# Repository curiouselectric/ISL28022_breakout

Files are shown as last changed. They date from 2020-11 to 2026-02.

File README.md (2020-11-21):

# ISL28022_breakout
This is a breakout board for the ISL28022 DC Power monitoring IC with I2C

The ISL28022 from Renesas has a datasheet available here: https://www.renesas.com/us/en/products/amplifiers-buffers/all-amplifiers/digital-power-monitors/device/ISL28022.html

It is a DC power monitoring IC, which measures current and voltage and calculates power. The data is read at either 14 or 15 bit resolution. Data can be obtained via an I2C connection.

The maximum voltage is 60V DC and the current can be up to 320mV measured across a current shunt.

This folder contains the PCB design files for a simple break out board which can be connected to a microcontroller of your choice.

It is available to buy here: https://www.curiouselectric.co.uk/

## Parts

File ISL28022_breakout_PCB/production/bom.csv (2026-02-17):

Designator | Footprint | Quantity | Value | LCSC Part #
C1 | SM_C_0805 | 1 | 100n
C2 | SM_R_1206 | 1 | 2.2u
C3 | SM_R_1206 | 1 | 1u
C4, C5 | SM_C_0805 | 2 | 10n
J1, J2 | SIL-4_Grove_Labelled_Correct | 2 | DATA
J3 | SM_SOLDER_ID_4_WAY | 1 | ID_A0
J4 | SM_SOLDER_ID_4_WAY | 1 | ID_A1
J5 | PCB_60x55_outline | 1 | PCB
J6 | 2019_011_16_CuriousElectricCompany_Logo_Round_Logo_No_words_KiCAD_10mm_PCBLogo | 1 | LOGO1
J7 | TCEC_Words_13mm | 1 | LOGO2
J8 | TH_SIL-2_screw_terminal_32A_LARGE | 1 | INPUT
J9 | TH_SIL-2_screw_terminal_32A_LARGE | 1 | OUTPUT
R1, R2 | SM0805 | 2 | 4.7k
R3, R4, R5 | SM0805 | 3 | 470R
R6 | Rshunt_universal | 1 | R_SHUNT
U1 | MSOP10-0.5 | 1 | ISL28022

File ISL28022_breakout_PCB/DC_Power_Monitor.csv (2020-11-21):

Source: | G:\My Drive\Work - Kits\PRODUCTS\Prototype\DC_Power_Monitor\DC_Power_Monitor.sch
Date: | 26/10/2020 18:13
Tool: | Eeschema (5.1.0)-1
Generator: | C:\Program Files\KiCad\bin\scripting\plugins/bom_csv_grouped_by_value.py
Component Count: | 21
Individual Components:
Item | Qty | Reference(s) | Value | LibPart | Footprint | Datasheet | Code | Cost | Description | Notes | Supplier
 |  | C1 | 100n | Device:C | REInnovationFootprint:SM_C_0805 | http://www.farnell.com/datasheets/1870456.pdf | 2320793 | ~ | 25V | ~ | Farnell
 |  | C2 | 2.2u | Device:C | REInnovationFootprint:SM0805 | http://www.farnell.com/datasheets/1769893.pdf | 2426966RL | ~ | 100V | ~ | Farnell
 |  | C3 | 1u | Device:C | REInnovationFootprint:SM_R_1206 | http://www.farnell.com/datasheets/84526.pdf | 1657939 | ~ | 100V | ~ | Farnell
 |  | C4 | 10n | Device:C | REInnovationFootprint:SM0805 | http://www.farnell.com/datasheets/1870456.pdf | 2320786 | ~ | 100V | ~ | Farnell
 |  | C5 | 10n | Device:C | REInnovationFootprint:SM0805 | http://www.farnell.com/datasheets/1870456.pdf | 2320786 | ~ | 100V | ~ | Farnell
 |  | J1 | DATA | Connector_Generic:Conn_01x04 | REInnovationFootprint:SIL-4_Grove_Labelled | ~
 |  | J2 | DATA | Connector_Generic:Conn_01x04 | REInnovationFootprint:SIL-4_Grove_Labelled | ~
 |  | J3 | ID_A0 | Connector_Generic:Conn_01x05 | REInnovationFootprint:TH_SIL_5_1mm | ~
 |  | J4 | ID_A1 | Connector_Generic:Conn_01x05 | REInnovationFootprint:TH_SIL_5_1mm | ~
 |  | J5 | PCB | Connector_Generic:Conn_01x01 | REInnovationFootprint:PCB_50x50_outline | ~
 |  | J6 | LOGO1 | Connector_Generic:Conn_01x01 | CuriousElectric3:2019_011_16_CuriousElectricCompany_Logo_Round_Logo_No_words_KiCAD_10mm_PCBLogo | ~
 |  | J7 | LOGO2 | Connector_Generic:Conn_01x01 | CuriousElectric3:TCEC_Words_13mm | ~
 |  | J8 | INPUT | Connector_Generic:Conn_01x02 | REInnovationFootprint:TH_CONN_2W | ~
 |  | J9 | OUTPUT | Connector_Generic:Conn_01x02 | REInnovationFootprint:TH_CONN_2W | ~
 |  | R1 | 4.7k | Device:R | REInnovationFootprint:SM0805 | http://www.farnell.com/datasheets/1849611.pdf | 2447385 | ~ | 100mW | ~ | Farnell
 |  | R2 | 4.7k | Device:R | REInnovationFootprint:SM0805 | http://www.farnell.com/datasheets/1849611.pdf | 2447385 | ~ | 100mW | ~ | Farnell
 |  | R3 | 470R | Device:R | REInnovationFootprint:SM0805 | http://www.farnell.com/datasheets/1849611.pdf | 2447374 | ~ | 100mW | ~ | Farnell
 |  | R4 | 470R | Device:R | REInnovationFootprint:SM0805 | http://www.farnell.com/datasheets/1849611.pdf | 2447374 | ~ | 100mW | ~ | Farnell
 |  | R5 | 470R | Device:R | REInnovationFootprint:SM0805 | http://www.farnell.com/datasheets/1849611.pdf | 2447374 | ~ | 100mW | ~ | Farnell
 |  | R6 | R_SHUNT | Device:R | matts_components:Rshunt_universal | http://www.farnell.com/datasheets/1755795.pdf | 2331878 | ~ | 500mW | ~ | Farnell
 |  | U1 | ISL28022 | matts_components:ISL28022 | REInnovationFootprint:MSOP10-0.5 | http://www.farnell.com/datasheets/1758637.pdf | 2373594 | ~ | I2C power monitor | ~ | Farnell
Collated Components:
Item | Qty | Reference(s) | Value | LibPart | Footprint | Datasheet | Code | Cost | Description | Notes | Supplier
1 | 1 | C1 | 100n | Device:C | REInnovationFootprint:SM_C_0805 | http://www.farnell.com/datasheets/1870456.pdf | 2320793 | ~ | 25V | ~ | Farnell
2 | 1 | C2 | 2.2u | Device:C | REInnovationFootprint:SM0805 | http://www.farnell.com/datasheets/1769893.pdf | 2426966RL | ~ | 100V | ~ | Farnell
3 | 1 | C3 | 1u | Device:C | REInnovationFootprint:SM_R_1206 | http://www.farnell.com/datasheets/84526.pdf | 1657939 | ~ | 100V | ~ | Farnell
4 | 2 | C4, C5 | 10n | Device:C | REInnovationFootprint:SM0805 | http://www.farnell.com/datasheets/1870456.pdf | 2320786 | ~ | 100V | ~ | Farnell
5 | 2 | J1, J2 | DATA | Connector_Generic:Conn_01x04 | REInnovationFootprint:SIL-4_Grove_Labelled | ~
6 | 1 | J3 | ID_A0 | Connector_Generic:Conn_01x05 | REInnovationFootprint:TH_SIL_5_1mm | ~
7 | 1 | J4 | ID_A1 | Connector_Generic:Conn_01x05 | REInnovationFootprint:TH_SIL_5_1mm | ~
8 | 1 | J5 | PCB | Connector_Generic:Conn_01x01 | REInnovationFootprint:PCB_50x50_outline | ~
9 | 1 | J6 | LOGO1 | Connector_Generic:Conn_01x01 | CuriousElectric3:2019_011_16_CuriousElectricCompany_Logo_Round_Logo_No_words_KiCAD_10mm_PCBLogo | ~
10 | 1 | J7 | LOGO2 | Connector_Generic:Conn_01x01 | CuriousElectric3:TCEC_Words_13mm | ~
11 | 1 | J8 | INPUT | Connector_Generic:Conn_01x02 | REInnovationFootprint:TH_CONN_2W | ~
12 | 1 | J9 | OUTPUT | Connector_Generic:Conn_01x02 | REInnovationFootprint:TH_CONN_2W | ~
13 | 2 | R1, R2 | 4.7k | Device:R | REInnovationFootprint:SM0805 | http://www.farnell.com/datasheets/1849611.pdf | 2447385 | ~ | 100mW | ~ | Farnell
14 | 3 | R3, R4, R5 | 470R | Device:R | REInnovationFootprint:SM0805 | http://www.farnell.com/datasheets/1849611.pdf | 2447374 | ~ | 100mW | ~ | Farnell
15 | 1 | R6 | R_SHUNT | Device:R | matts_components:Rshunt_universal | http://www.farnell.com/datasheets/1755795.pdf | 2331878 | ~ | 500mW | ~ | Farnell
16 | 1 | U1 | ISL28022 | matts_components:ISL28022 | REInnovationFootprint:MSOP10-0.5 | http://www.farnell.com/datasheets/1758637.pdf | 2373594 | ~ | I2C power monitor | ~ | Farnell

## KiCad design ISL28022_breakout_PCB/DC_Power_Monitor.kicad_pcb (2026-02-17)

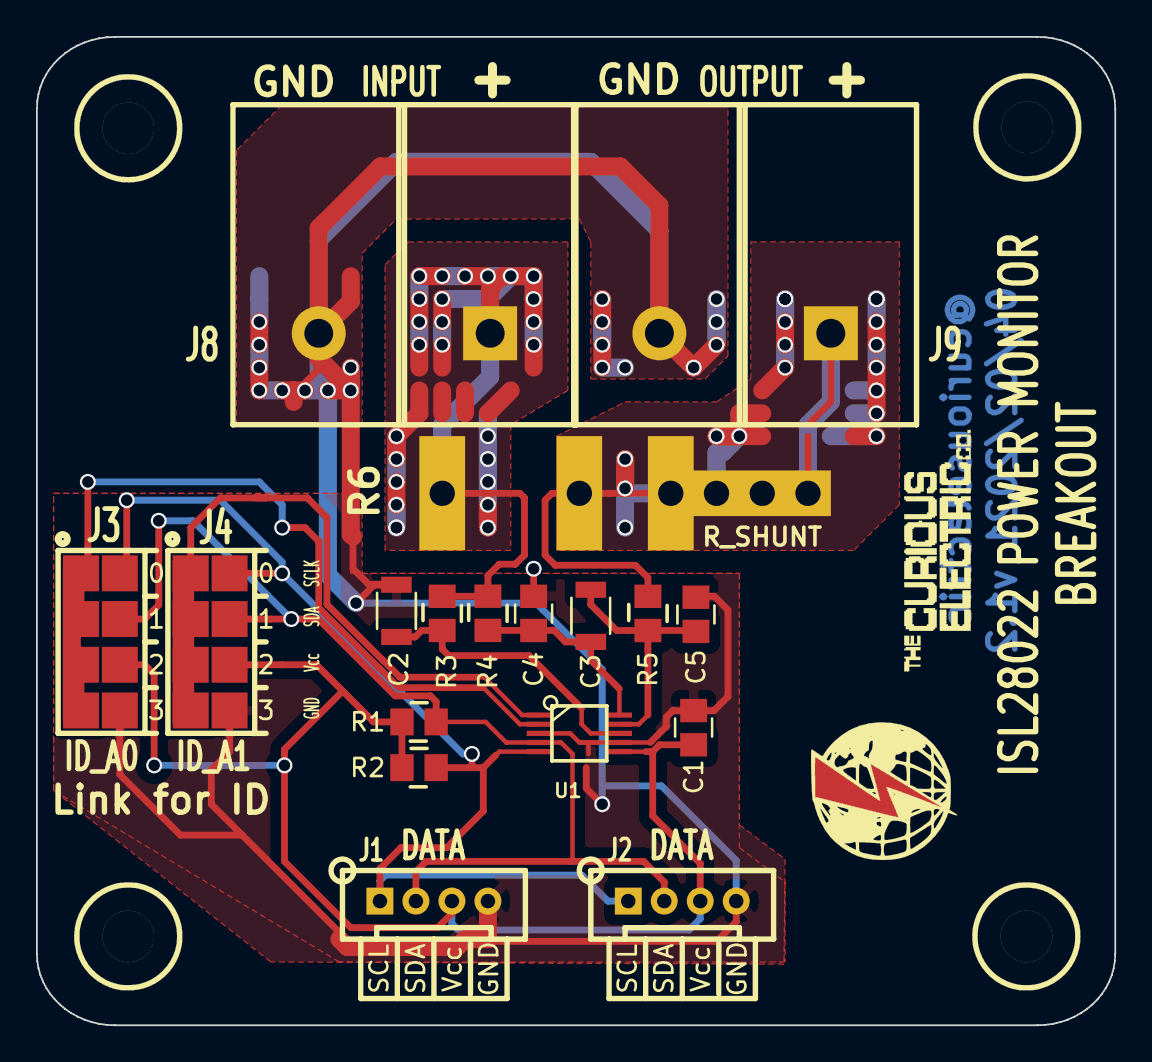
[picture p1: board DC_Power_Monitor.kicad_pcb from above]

Board: 2 copper layers, 59.9 x 54.9 mm, 21 parts (1 on the bottom side), 11 nets.

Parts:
C1: 100n; SM_C_0805
C2: 2.2u; SM_R_1206
C3: 1u; SM_R_1206
C4, C5: 10n; SM_C_0805
J1, J2: DATA; SIL-4_Grove_Labelled_Correct
J3: ID_A0; SM_SOLDER_ID_4_WAY
J4: ID_A1; SM_SOLDER_ID_4_WAY
J5: PCB; PCB_60x55_outline
J6: LOGO1; 2019_011_16_CuriousElectricCompany_Logo_Round_Logo_No_words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
J7: LOGO2; TCEC_Words_13mm
J8: INPUT; TH_SIL-2_screw_terminal_32A_LARGE
J9: OUTPUT; TH_SIL-2_screw_terminal_32A_LARGE
R1, R2: 4.7k; SM0805
R3, R4, R5: 470R; SM0805
R6: R_SHUNT; Rshunt_universal
U1: ISL28022; MSOP10-0.5

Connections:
/Ishn: J9.1, R5.2, R6.2
/Ishp: J8.1, R3.2, R4.2, R6.1
/SCLK: J1.1, J2.1, J3.2, J4.2, R2.1, U1.5
/SDA: J1.2, J2.2, J3.3, J4.3, R1.1, U1.4
/Vcc: C1.2, J1.3, J2.3, J3.4, J4.4, R1.2, R2.2, U1.6
GND: C1.1, C2.2, C4.2, C5.2, J1.4, J2.4, J3.5, J4.5, J8.2, J9.2, U1.3, U1.7
unnamed: C2.1, R3.1, U1.8
unnamed: C3.1, C4.1, R4.1, U1.10
unnamed: C3.2, C5.1, R5.1, U1.9
unnamed: J3.1, U1.2
unnamed: J4.1, U1.1

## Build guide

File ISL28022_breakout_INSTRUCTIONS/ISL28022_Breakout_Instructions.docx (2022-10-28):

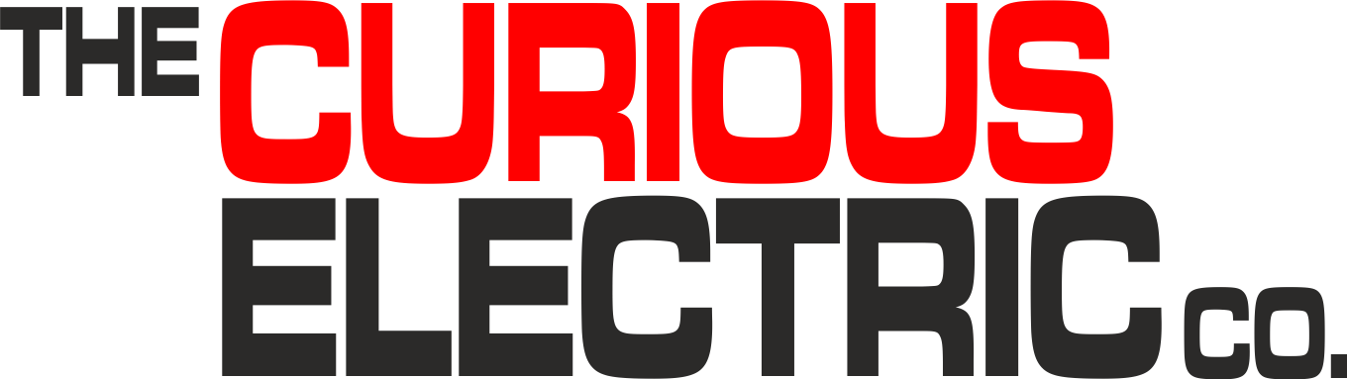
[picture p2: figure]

| DC Power Monitor Instructions

Date: | 28/10/2022 | Version: | 1.2 | By: | Matt Little

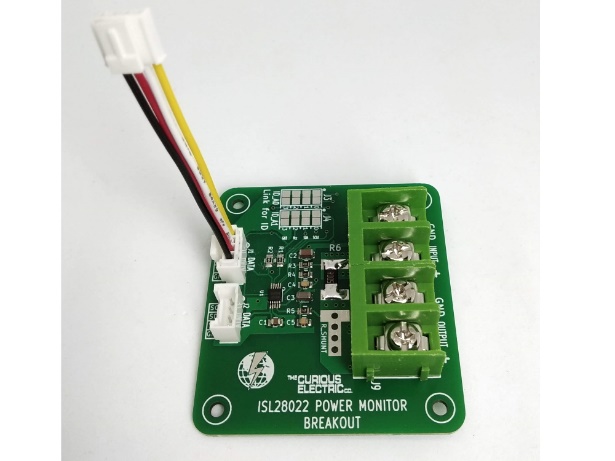
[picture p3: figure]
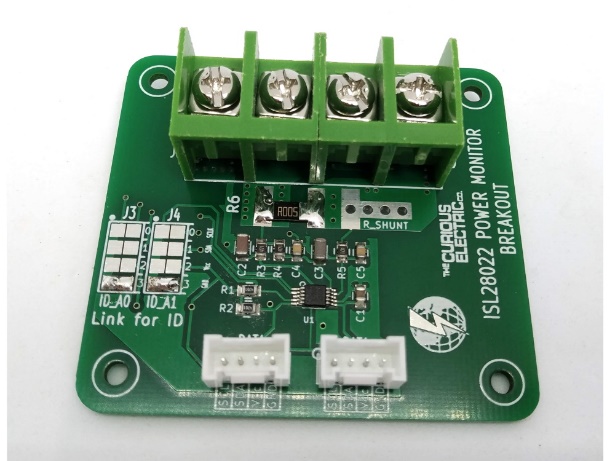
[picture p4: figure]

Need to measure DC voltage, current and power?

We needed to for a renewable energy project and saw the ISL28022 from Renesas:

https://www.renesas.com/eu/en/document/dst/isl28022-datasheet

This is a bidirectional high-side and low-side digital current sense and voltage monitor with an I2C serial interface.

It can measure up to 60V DC and current through a shunt resistor with a shunt voltage of up to 320mV. We supply a 5mOhm shunt resistor, which can measure up to 32 A. This is measured with a high-accuracy analogue to digital converter with better than 0.3%. It can have the shunt in the high or low side and can cope with negative shunt voltages.

We have put this IC on a circuit board with 25A rated screw terminals, ‘Grove’ connectors for the I2C interface. It can work with 3-5V power supply. We have added small smoothing capacitors and interface circuitry. This is surface mount & we have already added these components.

This is a reasonably simple kit which requires some soldering.

It will need wiring to a microcontroller of your choice through an I2C interface. We provide simple example Arduino Uno code.

It should take under 1 hour to build.

Not suitable for under 12 years old.

# Parts included:

| | | PCB with components

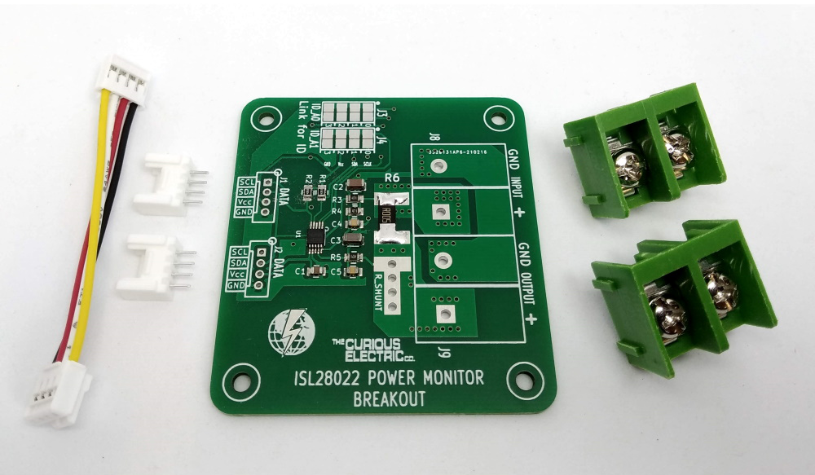
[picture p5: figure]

Grove connection cable
| | | | | | | Power Terminals (25A max) X 2
| | Grove Data connectors x 2 | | | 5 mOhm Shunt resistor (not shown)

# PCB Parts List:

Ref | Item | Quantity | Ref | Item | Quantity
C1 | 100nf capacitor (SMD Soldered) | 1 | J8, J9 | Input and Output 25A terminals | 2
C2 | 2.2uf capacitor (SMD Soldered) | 1 | R1, R2 | 4.7k (SMD – Not Used) | 2
C3 | 1uf capacitor (SMD Soldered) | 1 | R3, R4, R5 | 470R (SMD Soldered) | 3
C4, C5 | 10nf capacitor (SMD Soldered) | 2 | R6 | Shunt Resistor. (0.005 Ohm supplied). | 1
J1, J2 | DATA - Grove connector 4 way | 2 | U1 | ISL28022 Power Monitor (SMD Soldered) | 1
| PCB | 1

# Tools required:

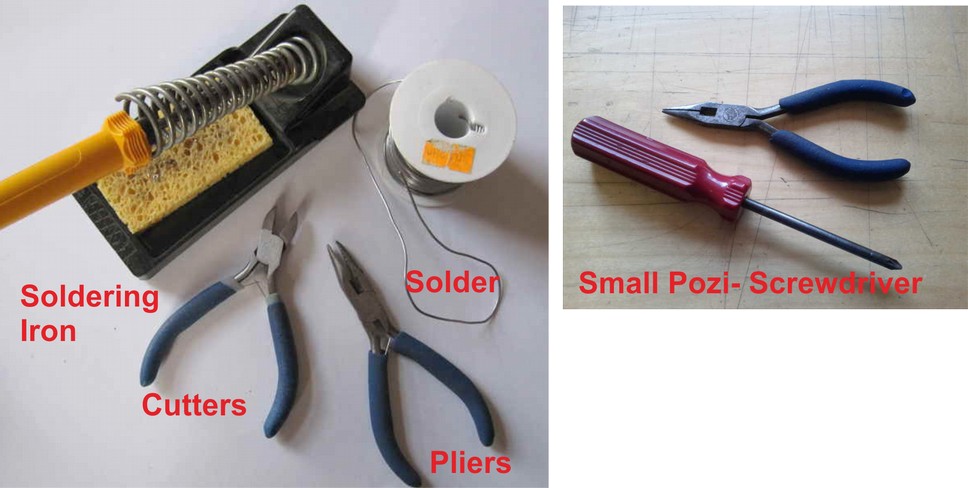
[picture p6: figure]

| | Long-nosed Pliers
Soldering Iron | | Posi-drive Screwdriver
Solder
Side cutters
Scissors (not shown)

# Instructions:

Step: 1 | Solder ‘Grove’ data connectors

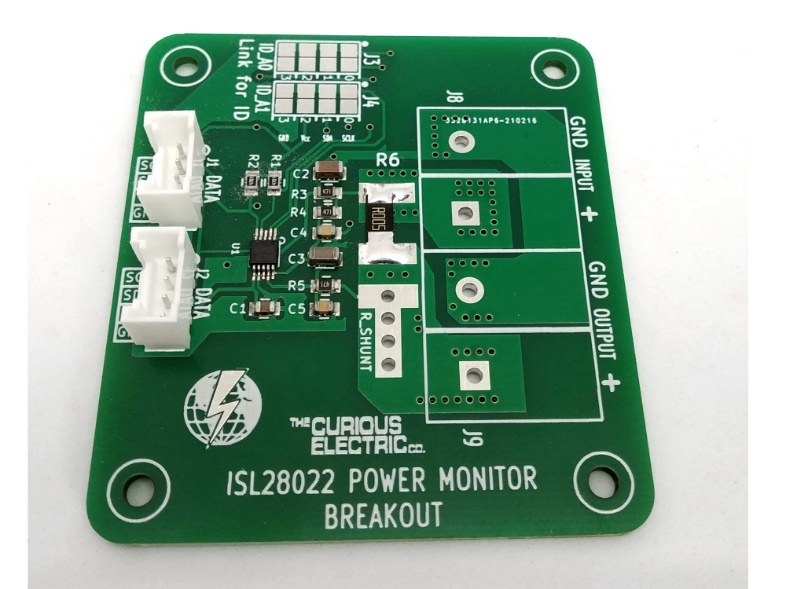
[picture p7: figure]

| | There are two 4-way ‘Grove’ connectors. This is a standard connector supplied by Seeed Studio (https://wiki.seeedstudio.com/Grove_System/) with lots of compatible boards. Place them into the 4-way holes in the PCB. Ensure that the silk-screen showing the notch is followed with the white connector. There is a small clip on the plug which needs to align with the notch on the socket.

Step: 2 | Solder shunt resistor

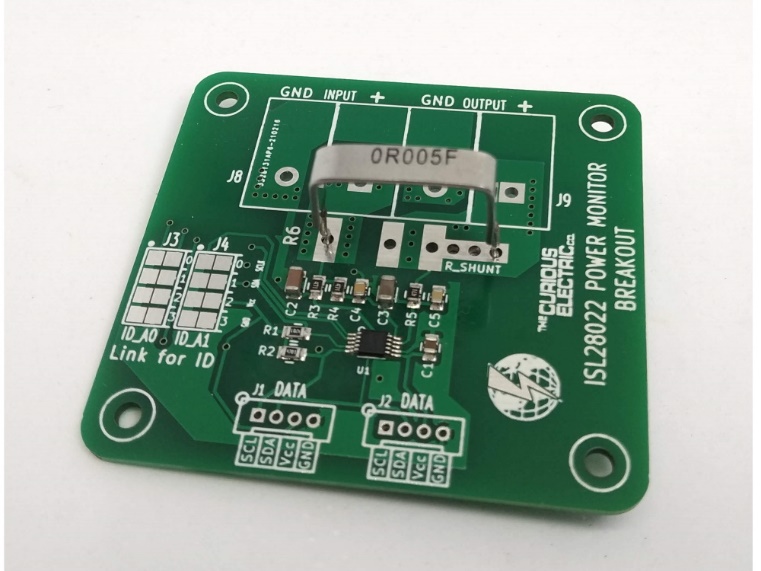
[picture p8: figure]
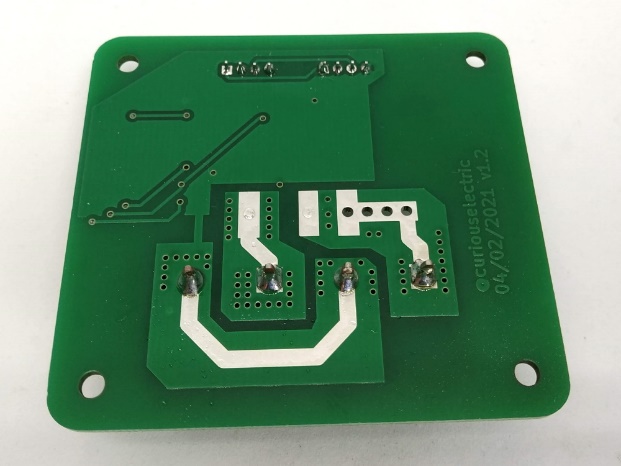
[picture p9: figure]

We provide a 5 milli-Ohm shunt resistor which is rated for 5W. This needs to be soldered into the universal shunt pads, as shown here. You can fit other resistors here, but you may need to change the example code. If you are going to use high currents (>10 A for extended periods), then you can add solder to the tracks to increase the current carrying capacity. Note: It is not recommended to use this board for more than 25 A for any length of time.

Step: 3 | Solder power terminals

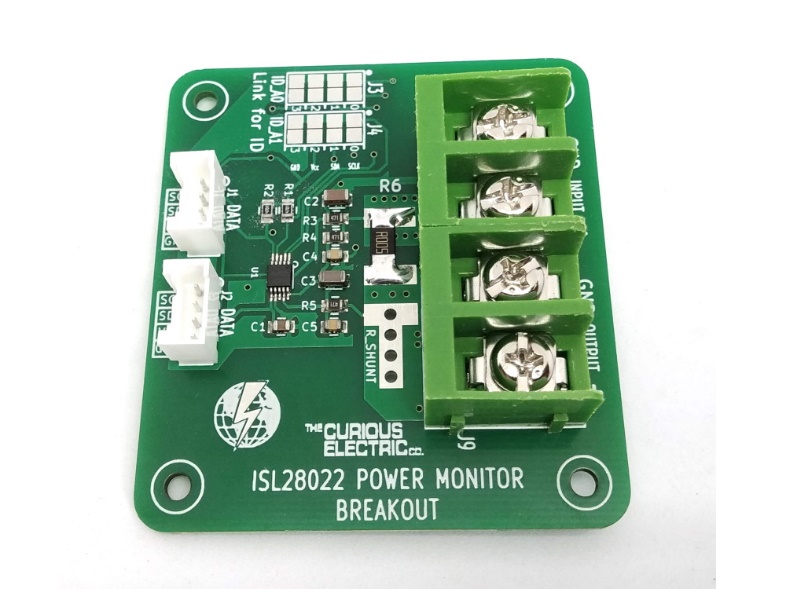
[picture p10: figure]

| | There are two 2-way screw terminal connectors for the power connections. These are rated to 25 A DC. They clip together with a small slot. They then fit through the holes. These can then be soldered. They may require quite a lot of solder and a powerful soldering iron, as they are large connectors.

Step: 4 | Solder ID connections

Each IC can have a different I2C address. This is enabled by connecting A0 and A1 to: GND, Vcc, SDA or SCL. This gives a total of 16 different addresses. These are given in the IC data sheet.

This is done by using a solder ‘blob’ to join two pads.

The connections to make depend upon the number of sensors you would like to attach.

Typically, one sensor is attached, so you just need a solder blob link connect A0 to GND (Link ID_A0 at pad 3) and A1 to GND (Link ID_A1 at pad 3), as per the code example. This is already done for you.

Remove the solder blob with a solder sucker if you want to change the ID.

Then add solder blobs as per the table under the photo.

There are more options than this, so check the data sheet for more information.

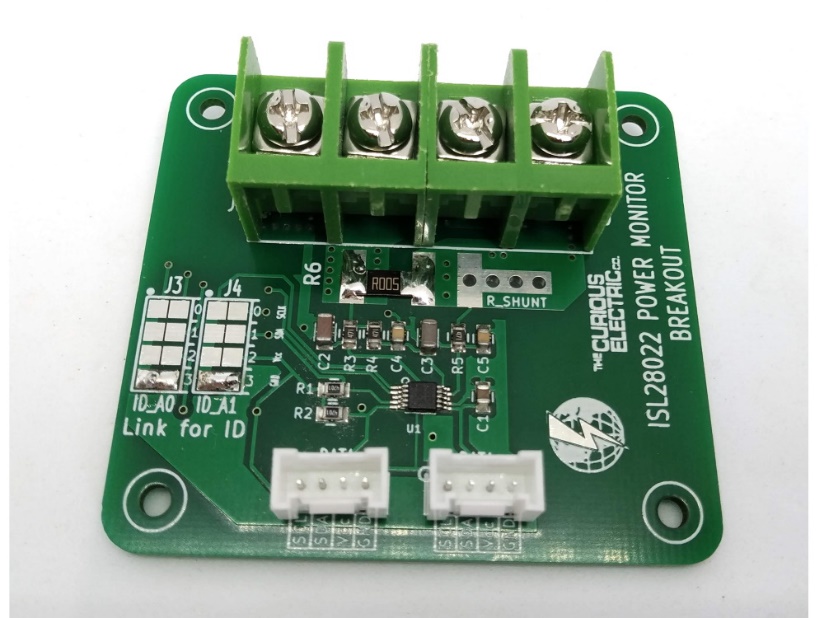
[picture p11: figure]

Link = add solder blob to the connector.

ID_A0 | ID_A1 | IC Address
Link 3 | Link 3 | 1000 000
Link 2 | Link 3 | 1000 001
Link 1 | Link 3 | 1000 010
Link 0 | Link 3 | 1000 011
Link 3 | Link 2 | 1000 100
Link 2 | Link 2 | 1000 101
Link 1 | Link 2 | 1000 110
Link 0 | Link 2 | 1000 111

Step: 5 | PCB is finished!

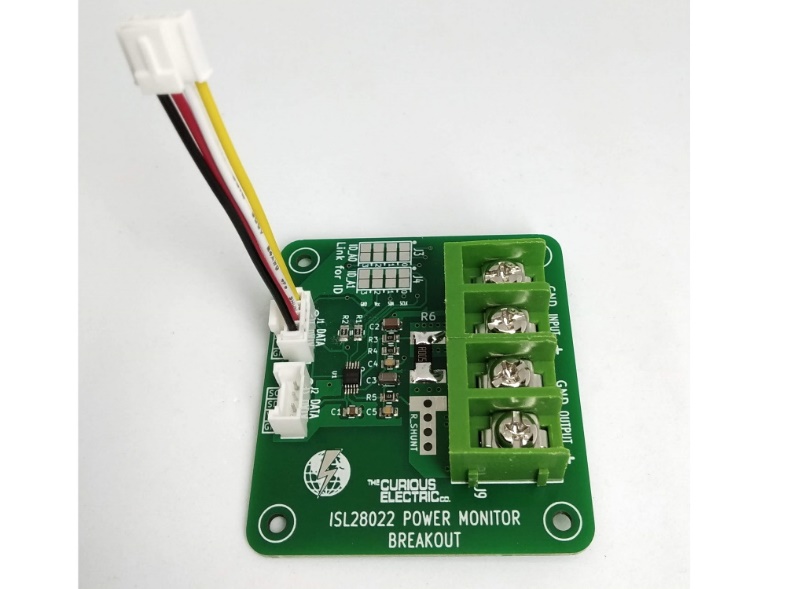
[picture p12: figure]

| | Have a nice cup of tea! You are now ready to try it out!

# Communication Instructions:

Step: 6 | Connect to your microcontroller of choice!

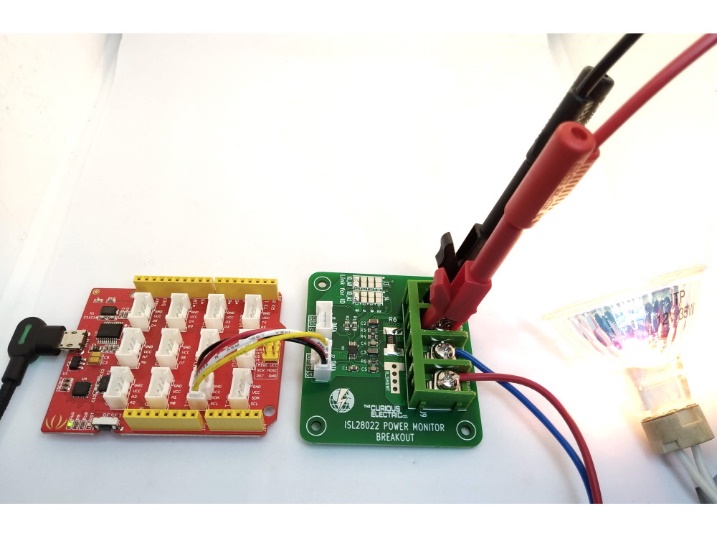
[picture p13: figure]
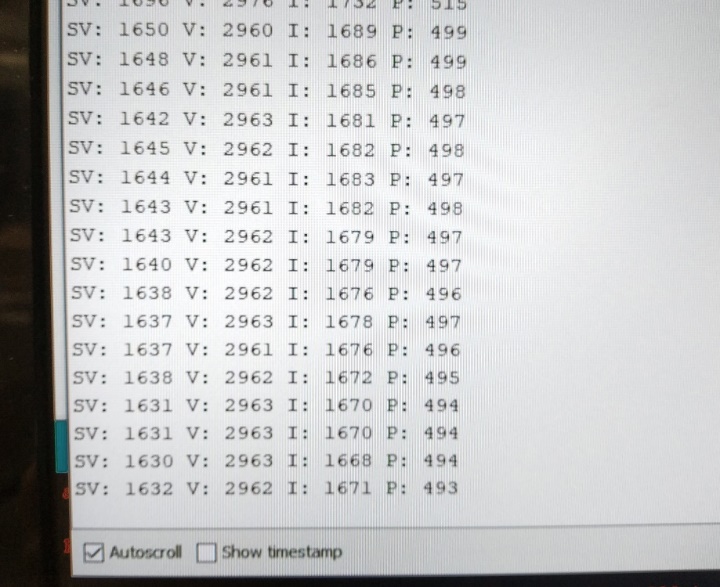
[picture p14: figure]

If you have a Grove board with an I2C connection, then please use the short connector wire to link the sensor with an I2C connection. The photo here shows testing with a “Seeeduino Lotus” board. Otherwise, you will need to make connections between GND, Vcc (which can be 3V3 or 5V) and then to the data (SDA) and clock (SCL) lines of your microcontroller. Upload the example code (this was tested with an Arduino Uno & Seeduino Lotus & Arduino Nano 33 IoT). You should see some serial data (at 9600 baud rate) showing the Shunt Voltage (mV), Voltage (V), Current (A) and Power (W).

# Testing & Fault Finding

These units have been tested in our lab, so hopefully no issues for you!

You want to try the simple example code and check that the readings look correct for the voltage and load you apply.

Any issues at all then try the following:

- Check soldering.
- Check power connections.
- Check I2C connections.
- Check microcontroller code updated correctly.

# Source Code and Design Files

These can be found, along with these instructions, in the repository here:

https://github.com/curiouselectric/ISL28022_breakout

# Contact details:

This kit has been designed and produced by:

The Curious Electric Company

hello@curiouselectric.co.uk

www.curiouselectric.co.uk

We would like you to be happy with this kit. If you are not happy for any reason, then please contact us and we will help to sort it out.

Please email hello@curiouselectric.co.uk with any questions or comments.

Please tweet us at @curiouselectric

If any parts are missing from your kit, then please email hello@curiouselectric.co.uk with details, including where the kit was purchased.

More information can be found via www.curiouselectric.co.uk

# Circuit Schematic:

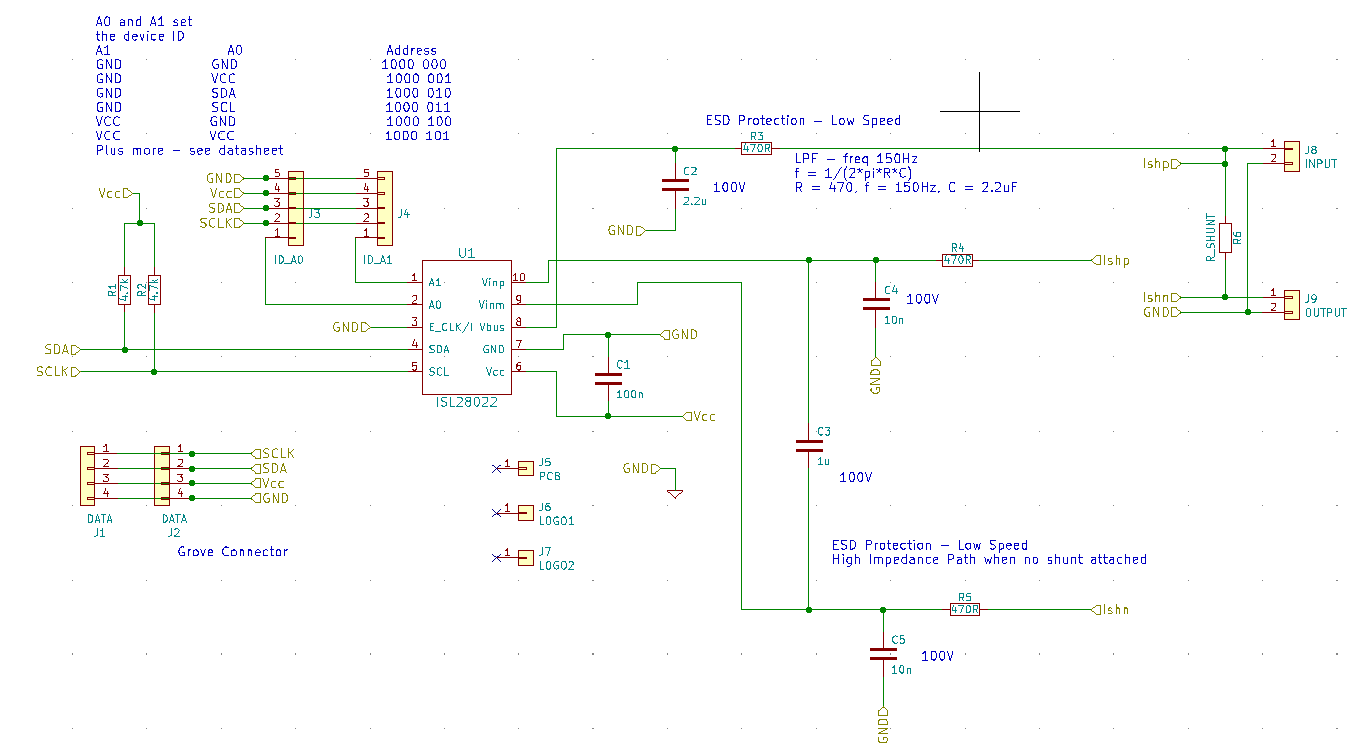
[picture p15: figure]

# PCB:

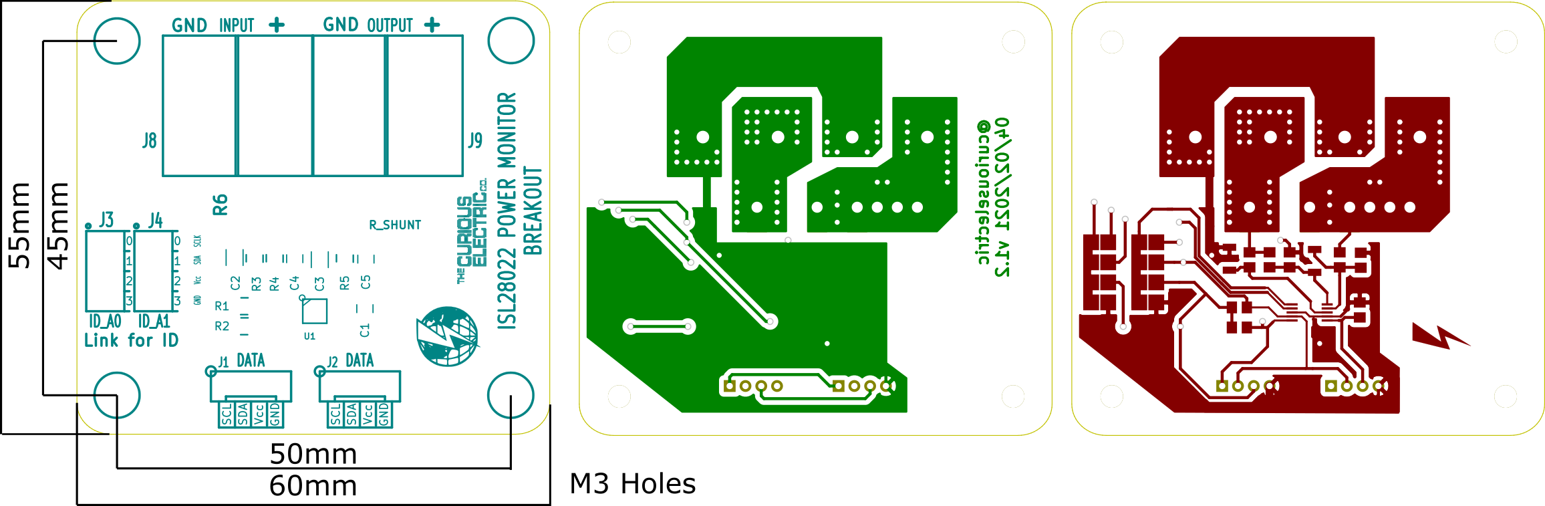
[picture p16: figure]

(Not to scale)

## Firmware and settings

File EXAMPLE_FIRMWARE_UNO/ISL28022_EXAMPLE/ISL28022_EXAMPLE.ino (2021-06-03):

/*
    Example code for Arduino Uno to talk to ISL28022 Power Monitor IC
    Details and PCB design and instructions here
    https://github.com/curiouselectric/ISL28022_breakout  
*/

#include <Arduino.h>
#include <Wire.h>
#include "isl28022DL.h"

// The baud rate for serial communications
#define SERIAL_BAUD       9600

// This information is for the ISL28022 unit:
#define ADDRESS_ISL0    0b1000000  // This is the device address for A0 = GND A1 = GND
//#define ADDRESS_ISL1    0b1000001  // This is the device address for A0 = VCC A1 = GND
//#define ADDRESS_ISL2    0b1000010  // This is the device address for A0 = SDA A1 = GND

float dataValue;

void setup()
{
  // initialize serial communication:
  Serial.begin(9600);
  // Start up the ISL28022 Power monitor ICs
  power_monitor.begin(ADDRESS_ISL0);
}

void loop()
{
  dataValue = power_monitor.readRegister(ADDRESS_ISL0, SHUNTVOLTREG); 
  dataValue = power_monitor.readRegister(ADDRESS_ISL0, BUSVOLTREG);
  dataValue = power_monitor.readRegister(ADDRESS_ISL0, CURRENTREG);
  dataValue = power_monitor.readRegister(ADDRESS_ISL0, POWERREG);
  Serial.println();
  delay(1000);  // Check every second!
}

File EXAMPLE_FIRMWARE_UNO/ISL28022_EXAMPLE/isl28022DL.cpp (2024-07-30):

#include "isl28022DL.h"

void power_isl28022::begin(int _address)
{
  // Set up ISL28022 Power Monitor IC
  // Test the ISL28022
  Wire.begin();  // Join the bus as Master
  delay(20);  // Short settling delay
  // Reset the Configuration Register

  Serial.print("Start: ");
  Serial.println(_address);

  Wire.beginTransmission(_address);  // Start write to address 0b1000000
  Wire.write(0x00);    // Write to the calibration register

  // Set up everything:
  // RST/BRNG1/BRNG0/PG1/PG0/BADC3/BADC2/BADC1/BADC0/SADC3/SADC2/SADC1/SADC0/MODE2/MODE1/MODE0
  // Set it to:
  // 0b1000000000000000
  // Perform a system reset:
  Wire.write (0b10000000);
  Wire.write (0b00000000);
  Wire.endTransmission();

  // Set up the Configuration Register
  Wire.beginTransmission(_address);  // Start write to address 0b1000000
  Wire.write(0x00);    // Write to the calibration register

  // Set up everything:
  // RST/BRNG1/BRNG0/PG1/PG0/BADC3/BADC2/BADC1/BADC0/SADC3/SADC2/SADC1/SADC0/MODE2/MODE1/MODE0
  // Shunt with 320mV range so need to set PG1 = 1 and PG0 = 1 (from datasheet)
  // Set it to:
  // 0b 0 11 11 0011 0011 111
  Wire.write (0b01111001);
  Wire.write (0b10011111);
  Wire.endTransmission();

  // Set up the Calibration Register
  // This allows the Power and Current registers to be used
  Wire.beginTransmission(_address);  // Start write to IC address 
  Wire.write(0x05);                 // Write to the calibration register

  // OLD values were:
  // 4474 = 117A in HEX
  // Binary: 0001 0001 0111 1010

  // 5mOhm Shunt with 320mV range
  // Calibration register needs to be set to 4194 (dec) = 1062 (hex)
  Wire.write (0x10);
  Wire.write (0x62);

  Wire.endTransmission();
}

// Read data from a specified register and apecified IC address:
float power_isl28022::readRegister(int _address, int _reg)
{
  // This subroutine reads data from device with I2C address ADDRESS
  // It reads the data from the device register ISL28022register
  byte firstByte = 0;
  byte secondByte = 0;
  uint16_t valueInt16;
  float  valueFloat;

  Wire.beginTransmission(_address);  // Start write to address 0b1000000
  Wire.write(_reg);     // Read the Bus Voltage register
  Wire.endTransmission();
  Wire.requestFrom(_address, 2);    // Read two bytes of data

  while (!Wire.available())          // Wait until there is data returned
  {
  }
  firstByte = Wire.read();          // Read and store the data
  secondByte = Wire.read();

  if (_reg == SHUNTVOLTREG)
  {
    Serial.print(F("SV: "));
    // ****THIS DEPENDS UPON THE SADC BITS*******
    // ****RANGE = 11 (full scale up to +/-160mV)
    // The bus voltage is a 15 bit value which needs to be converter.
    // Bit 16 is a sign bit (2's complement?)
    // Need to add them together, with the correct weighting factor (256)
    valueInt16 = firstByte * 256 + secondByte; // Convert to a value
    // Each bit is (160mV / 2^15)
    // So value * 0.00001V = shunt voltage
    // This is too small, so keep number in milli Volts
    valueFloat = ((valueInt16 * 320.0) / 32768.0);
  }

  else if (_reg == BUSVOLTREG)
  {
    Serial.print(F("V: "));
    // ****THIS DEPENDS UPON THE RANGE BITS*******
    // ****RANGE = 11 (up to 60V)
    // Need to add them together, with the correct weighting factor (256)
    valueInt16 = firstByte * 256 + secondByte; // Convert to a value
    valueInt16 = valueInt16 >> 2; // Shift the value across by 2 (14 bit number)

    // 60V = max bus range This is 14 bit number
    // Each LSB is 4mV so multiply up
    valueFloat = valueInt16 * 0.004;
  }
  else if (_reg == POWERREG)
  {
    Serial.print(F("P: "));
    // Only has meaning if calibration register (0x05) is programmed.
    valueInt16 = firstByte * 256 + secondByte; // Convert to a value
    // From ISL28022 datasheet
    // Actual Power = reading * Power LSB * 5000 * 2
    // Power LSB = Current LSB x Voltage LSB
    // Power LSB = 1.953125 mA x 4 mV = 7.8125 uW per LSB
    // 1 LSB = 7.8125uW
    valueFloat = (valueInt16 * 7.8125 * 5000.0 * 2.0) / 1000000.0;
  }
  else if (_reg == CURRENTREG)
  {
    Serial.print(F("I: "));
    // Only has meaning if calibration register (0x05) is programmed.
    valueInt16 = firstByte * 256 + secondByte; // Convert to a value
    // From ISL28022 datasheet
    // Actual current = ((reading / 2^15) * Max Shunt Voltage (mV)) / Shunt resistance(mOhm)
    valueFloat = ((valueInt16 / 32768.0) * 320.0) / 5.0 ;
  }
  Serial.print(valueFloat, 2);
  Serial.print(" ");

  return valueFloat;
}

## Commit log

2020-11-21 Update with PCB added
    [DC_Power_Monitor.csv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]
2021-06-03 updated PCB and instructions
    [DC_Power_Monitor-B_Cu.gbl, DC_Power_Monitor-B_Mask.gbs, DC_Power_Monitor-Edge_Cuts.gm1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]
2021-06-07 updated instructions
    [DC_Power_Monitor.kicad_pcb]
2024-07-30 Updated for higher voltage
    Changed int16_t to uint16_t to deal with higher numbers.
